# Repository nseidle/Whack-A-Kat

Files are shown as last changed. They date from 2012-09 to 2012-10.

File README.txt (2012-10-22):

WAK-A-KAT was a project for Burning Man 2012. This is a reaction speed game based on the Wack-A-Mole game. 6 pipes stuck out of the ground about 3 feet tall. At the end of the two rows of pipes (three each) stood a gum ball dispenser. The dispenser was filled full of cat foot.

On the end of each pipe was a large carnival button. Buttons would randomly illuminate and the player would have to hit the button(s) as fast as they could. Throughout the night the game would average the scores together. If you had a score that was better than the average (less total time to complete the game), then you won! And the gum ball dispenser, modified with a continuous servo, would dispense an amount of dry cat food. Yum!

This project was one of the first where I used the Arduino Mega 2560. The PCB layout is a decent example of a shield design for the Mega.

I also used Bill Porter's MP3 library: http://www.billporter.info/sparkfun-mp3-shield-arduino-library/
You rock Bill!

Each pipe was wrapped in EL wire. This provided a level of safety but used quite a bit more power than I predicted causing the 12V battery to drain before the night was over. Lesson: measure your project's power usage before you assume a brick of a battery will do the job.

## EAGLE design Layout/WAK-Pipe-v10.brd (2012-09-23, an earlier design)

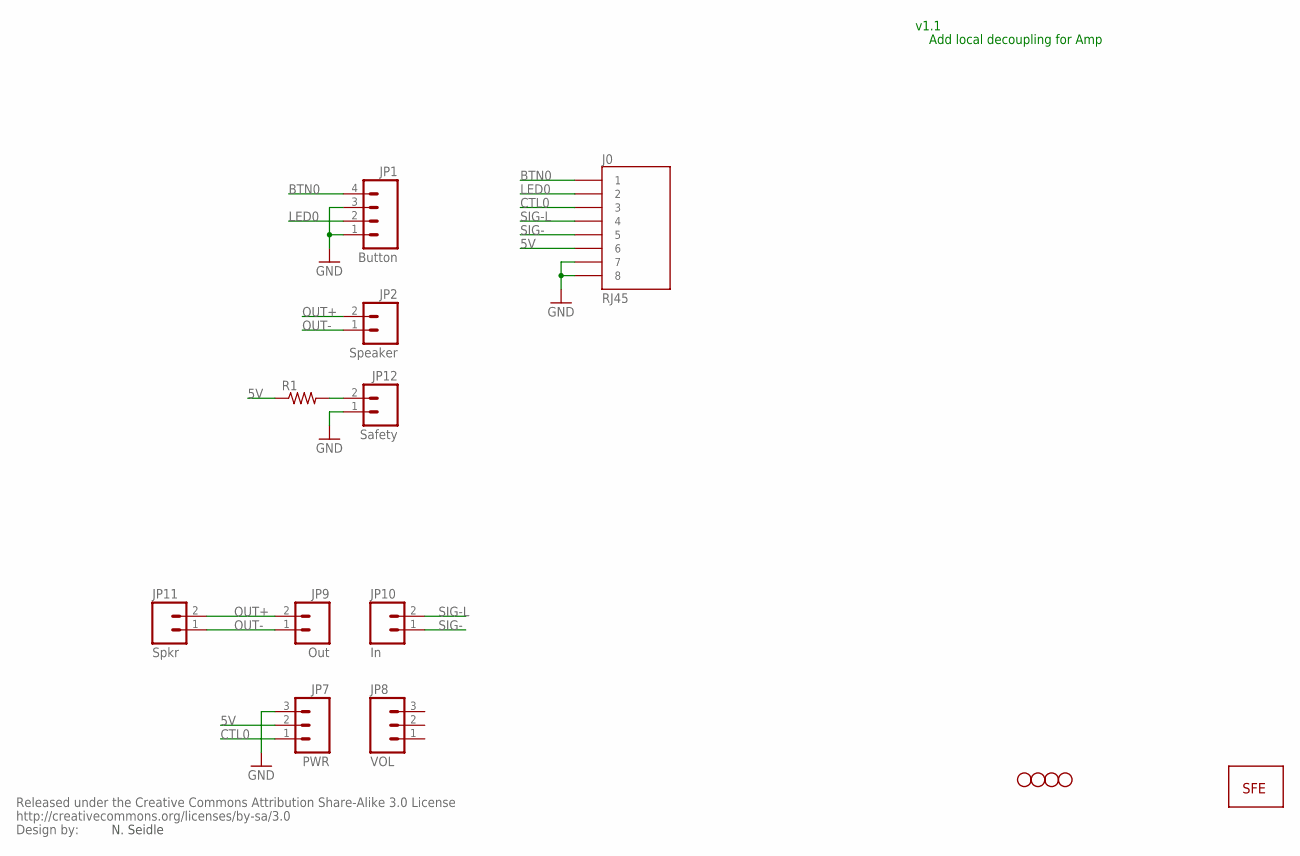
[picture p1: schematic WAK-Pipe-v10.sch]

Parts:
J0: RJ45; RJ45-8
JP1: Button; JST-4-PTH
JP2: Speaker; JST-2-PTH
JP3, JP4, JP5, JP6: STAND-OFF
JP7: PWR; 1X03
JP8: VOL; 1X03
JP9: Out; 1X02
JP10: In; 1X02
JP11: Spkr; 1X02
JP12: Safety; JST-2-PTH
R1: RESISTORAXIAL-0.3; AXIAL-0.3
U$1: LOGO-SFENEW; SFE-NEW-WEBLOGO
U$2: CREATIVE_COMMONS

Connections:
5V: J0.6, JP7.2, R1.P$1 (1)
BTN0: J0.1, JP1.4
CTL0: J0.3, JP7.1
GND: J0.7, J0.8, JP1.1, JP1.3, JP7.3, JP12.1
LED0: J0.2, JP1.2
unnamed: JP12.2, R1.P$2 (2)
OUT+: JP2.2, JP9.2, JP11.2
OUT-: JP2.1, JP9.1, JP11.1
SIG-: J0.5, JP10.1
SIG-L: J0.4, JP10.2

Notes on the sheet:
N. Seidle
v1.1
Add local decoupling for Amp

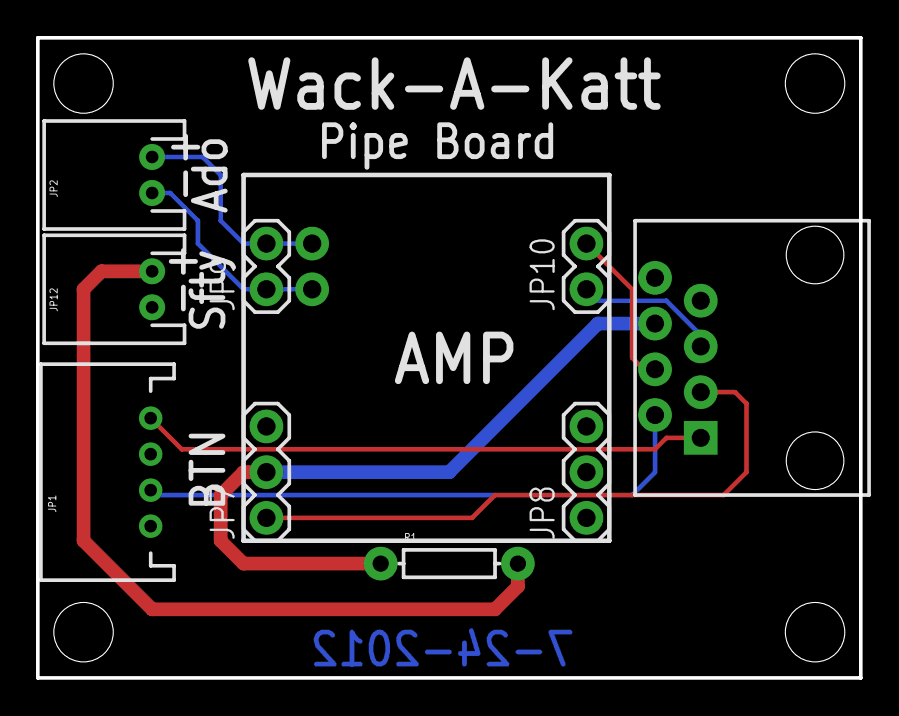
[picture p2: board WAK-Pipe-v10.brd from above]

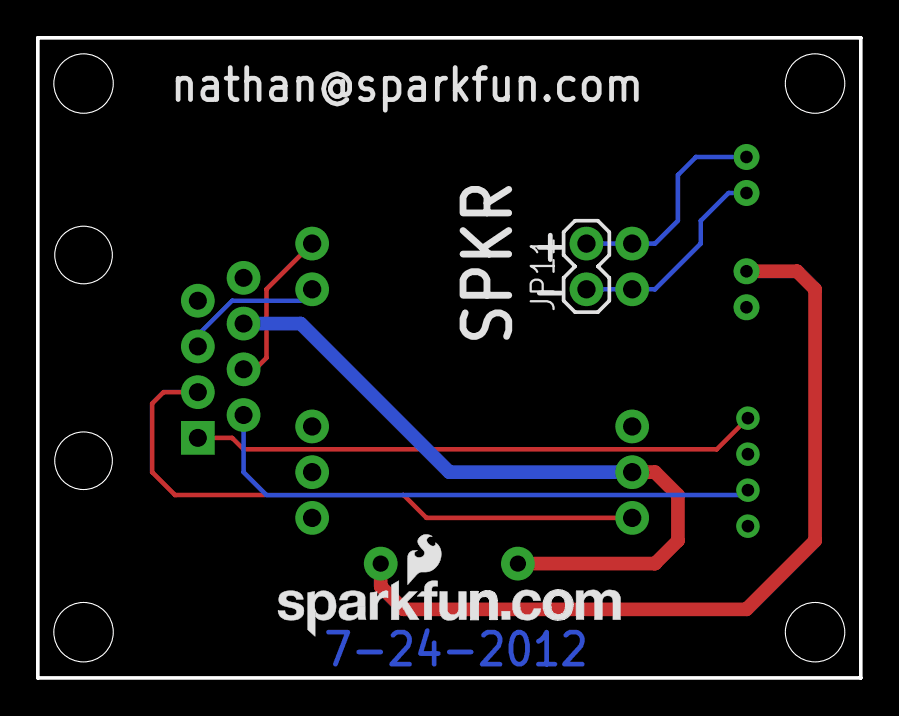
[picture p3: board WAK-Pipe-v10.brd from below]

Board: 2 copper layers, 45.7 x 35.6 mm, 16 parts (2 on the bottom side), 10 nets.

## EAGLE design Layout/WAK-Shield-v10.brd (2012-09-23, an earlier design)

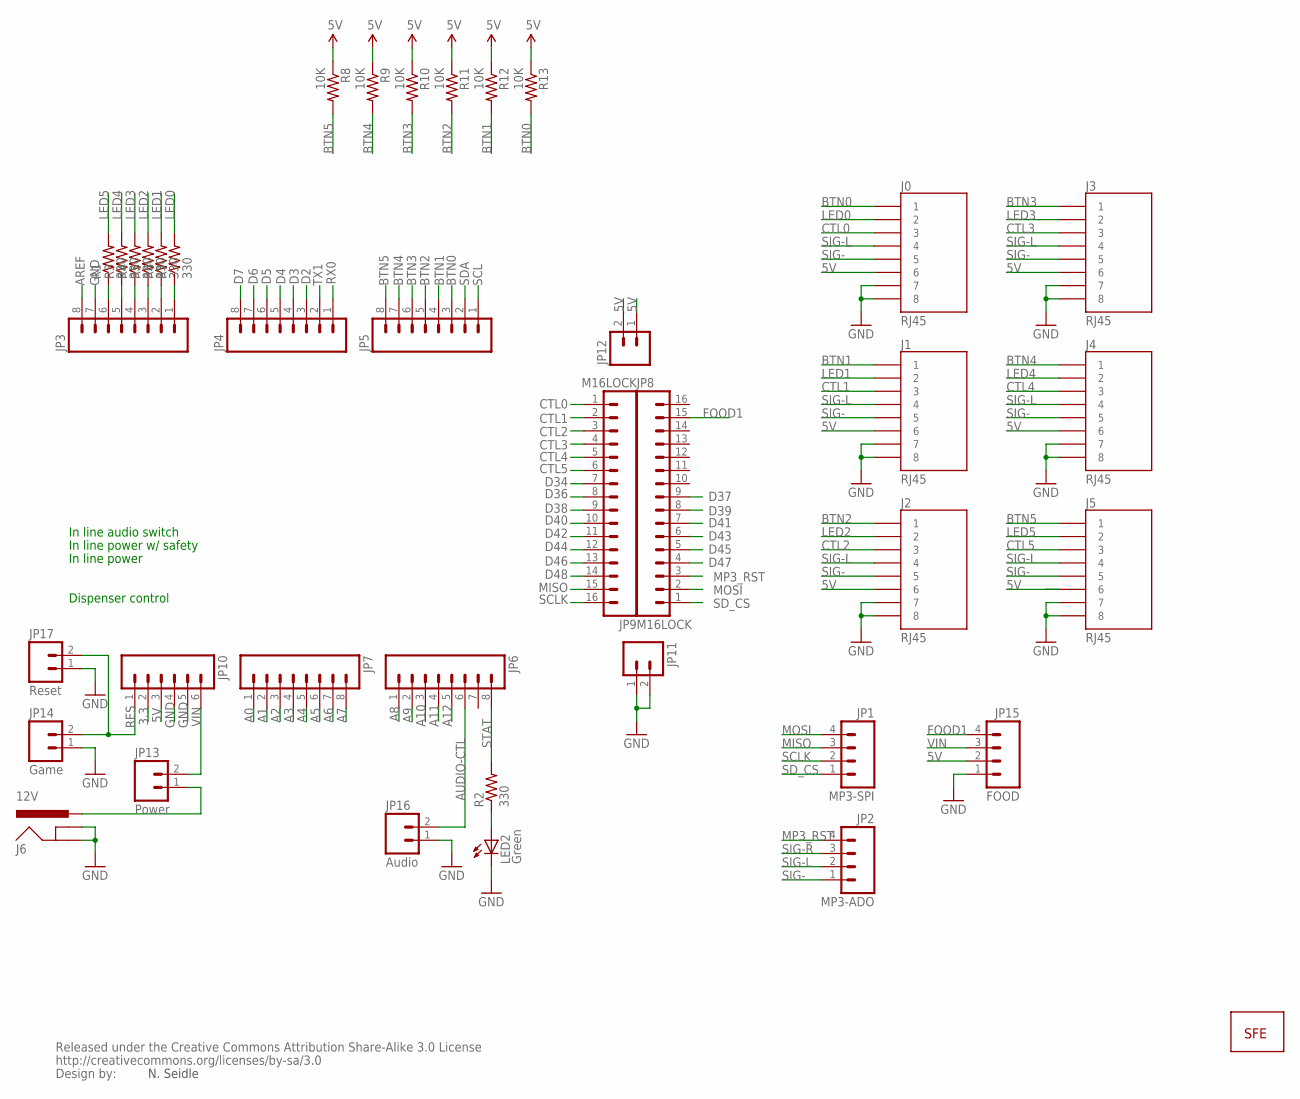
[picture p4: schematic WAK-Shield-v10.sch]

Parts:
J0, J1, J2, J3, J4, J5: RJ45; RJ45-8
J6: 12V; POWER_JACK_PTH_LOCK
JP1: MP3-SPI; JST-4-PTH
JP2: MP3-ADO; JST-4-PTH
JP3, JP4, JP5, JP6, JP7: M08LOCK; 1X08_LOCK
JP8, JP9: M16LOCK; 1X16_LOCK
JP10: M06LOCK; 1X06_LOCK
JP11, JP12: M02LOCK; 1X02_LOCK
JP13: Power; 1X02
JP14: Game; 1X02
JP15: FOOD; JST-4-PTH
JP16: Audio; 1X02
JP17: Reset; SCREWTERMINAL-3.5MM-2
LED2: Green; LED5MM
R1, R2, R3, R4, R5, R6, R7: 330; AXIAL-0.3
R8, R9, R10, R11, R12, R13: 10K; AXIAL-0.3
U$1: LOGO-SFENEW; SFE-NEW-WEBLOGO
U$2: CREATIVE_COMMONS

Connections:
3.3: JP10.2
5V: J0.6, J1.6, J2.6, J3.6, J4.6, J5.6, JP10.3, JP12.1, JP12.2, JP15.2, R8.P$1 (1), R9.P$1 (1), R10.P$1 (1), R11.P$1 (1), R12.P$1 (1), R13.P$1 (1)
A0: JP7.1
A1: JP7.2
A2: JP7.3
A3: JP7.4
A4: JP7.5
A5: JP7.6
A6: JP7.7
A7: JP7.8
A8: JP6.1
A9: JP6.2
A10: JP6.3
A11: JP6.4
A12: JP6.5
AREF: JP3.8
AUDIO-CTL: JP6.6, JP16.2
BTN0: J0.1, JP5.3, R13.P$2 (2)
BTN1: J1.1, JP5.4, R12.P$2 (2)
BTN2: J2.1, JP5.5, R11.P$2 (2)
BTN3: J3.1, JP5.6, R10.P$2 (2)
BTN4: J4.1, JP5.7, R9.P$2 (2)
BTN5: J5.1, JP5.8, R8.P$2 (2)
CTL0: J0.3, JP9.1
CTL1: J1.3, JP9.2
CTL2: J2.3, JP9.3
CTL3: J3.3, JP9.4
CTL4: J4.3, JP9.5
CTL5: J5.3, JP9.6
D2: JP4.3
D3: JP4.4
D4: JP4.5
D5: JP4.6
D6: JP4.7
D7: JP4.8
D34: JP9.7
D36: JP9.8
D37: JP8.9
D38: JP9.9
D39: JP8.8
D40: JP9.10
D41: JP8.7
D42: JP9.11
D43: JP8.6
D44: JP9.12
D45: JP8.5
D46: JP9.13
D47: JP8.4
D48: JP9.14
FOOD1: JP8.15, JP15.4
GND: J0.7, J0.8, J1.7, J1.8, J2.7, J2.8, J3.7, J3.8, J4.7, J4.8, J5.7, J5.8, J6.GND, J6.GNDBREAK, JP3.7, JP10.4, JP10.5, JP11.1, JP11.2, JP14.1, JP15.1, JP16.1, JP17.1, LED2.K (C)
LED0: J0.2, R7.P$2 (2)
LED1: J1.2, R6.P$2 (2)
LED2: J2.2, R5.P$2 (2)
LED3: J3.2, R4.P$2 (2)
LED4: J4.2, R3.P$2 (2)
LED5: J5.2, R1.P$2 (2)
MISO: JP1.3, JP9.15
MOSI: JP1.4, JP8.2
MP3_RST: JP2.4, JP8.3
unnamed: JP3.6, R1.P$1 (1)
unnamed: JP3.5, R3.P$1 (1)
unnamed: JP3.4, R4.P$1 (1)
unnamed: JP3.3, R5.P$1 (1)
unnamed: JP3.2, R6.P$1 (1)
unnamed: JP3.1, R7.P$1 (1)
unnamed: J6.PWR, JP13.1
unnamed: LED2.A, R2.P$1 (1)
RES: JP10.1, JP14.2, JP17.2
RX0: JP4.1
SCL: JP5.1
SCLK: JP1.2, JP9.16
SDA: JP5.2
SD_CS: JP1.1, JP8.1
SIG-: J0.5, J1.5, J2.5, J3.5, J4.5, J5.5, JP2.1
SIG-L: J0.4, J1.4, J2.4, J3.4, J4.4, J5.4, JP2.2
SIG-R: JP2.3
STAT: JP6.8, R2.P$2 (2)
TX1: JP4.2
VIN: JP10.6, JP13.2, JP15.3

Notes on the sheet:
N. Seidle
In line audio switch
In line power w/ safety
In line power
Dispenser control

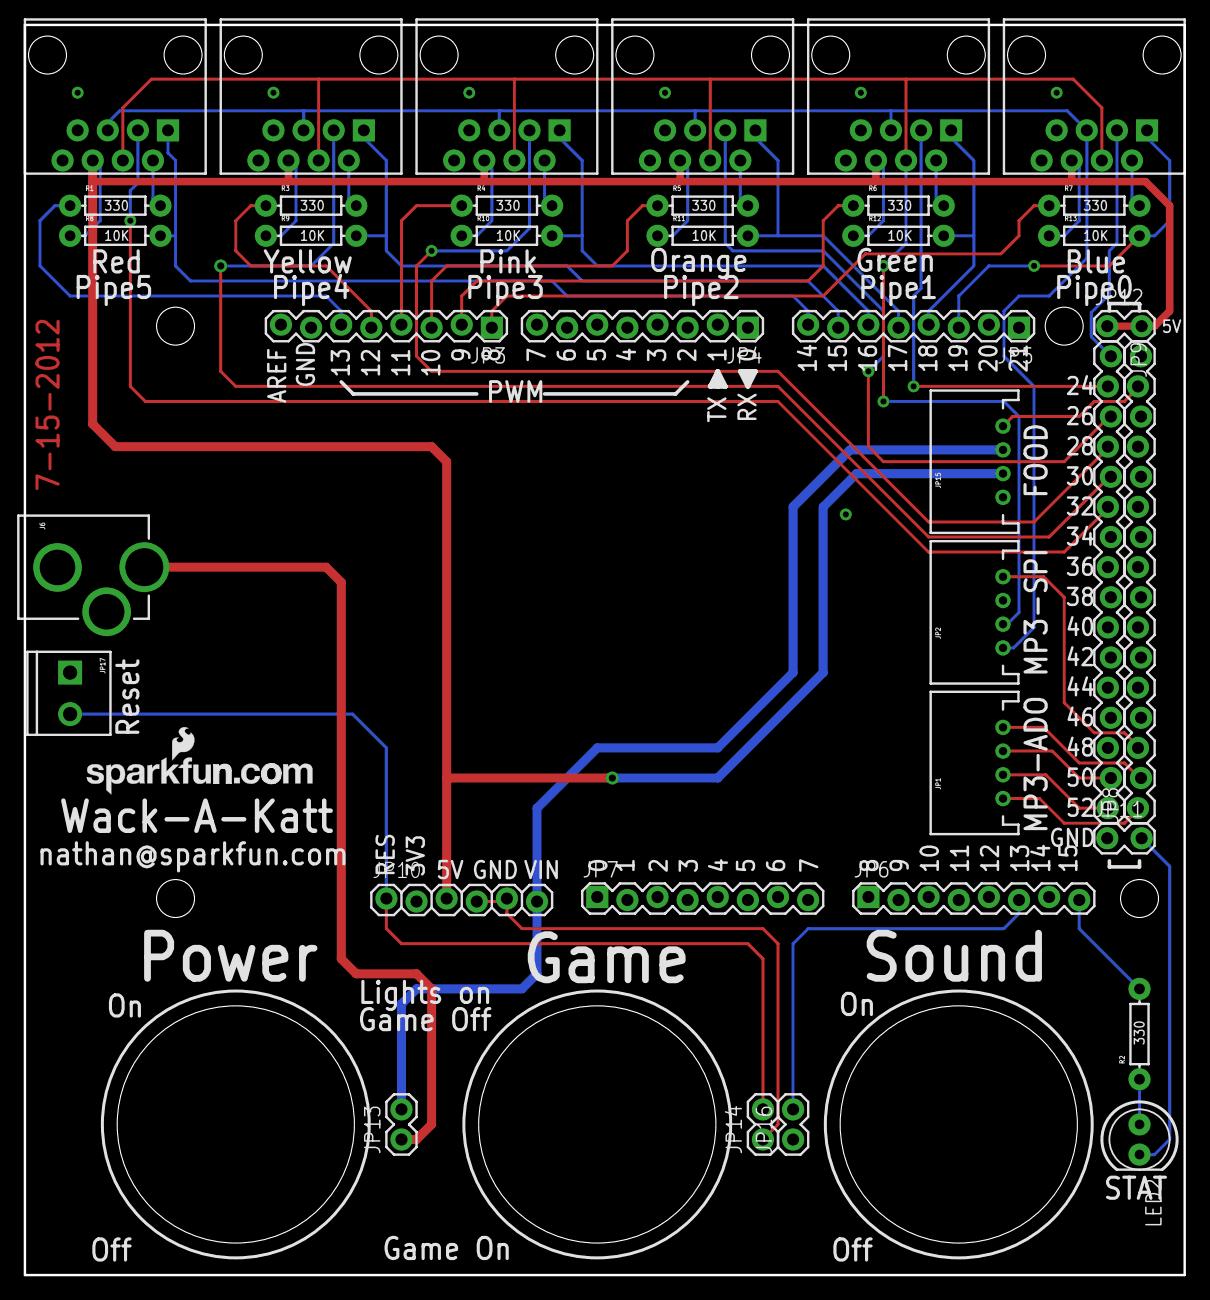
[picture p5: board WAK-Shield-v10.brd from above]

Board: 2 copper layers, 97.8 x 105.4 mm, 40 parts (0 on the bottom side), 40 nets.

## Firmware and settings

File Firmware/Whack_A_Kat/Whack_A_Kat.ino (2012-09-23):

/*
 4-28-2011
 Spark Fun Electronics 2011
 Nathan Seidle
 
 This code is public domain but you buy me a beer if you use this and we meet someday (Beerware license).
 
 This uses Bill Porter's exellent MP3 Shield Library
 
 There are 30 phases to WAK. Phase 1 has 1 button at a time and by phase 20 there are multiple buttons going
 at same time.
 
 Based on reaction time, the dispenser runs for different amounts of time.
 */

#include <SPI.h>

//Add the SdFat Libraries
#include <SdFat.h>
#include <SdFatUtil.h> 

#include <Servo.h> 

//and the MP3 Shield Library
#include <SFEMP3Shield.h>

//Create and name the library object
SFEMP3Shield MP3player;

//Create servo object
Servo foodServo;

//byte temp;
byte MP3result;

#define number_of_buttons  6 //The number of buttons available to hit
#define number_of_rounds 8 //The number of rounds the game will last

//We have to turn down the volume when all the cats are on otherwise the system will reset
//We can turn up the volume when individual cats are activated
#define ONECAT_VOLUME  30 //40 is ok, 20 is pretty stinking loud
#define ALLCAT_VOLUME  60 //Less then 60 and system will reset

//#define FOOD_AMOUNT 6700 //Three servings
#define FOOD_AMOUNT 6700/2 //Two servings
//#define FOOD_AMOUNT 6700/3 //One serving

int levels[number_of_rounds][number_of_buttons]; //Game board array
int level_times[number_of_rounds]; //Keeps track of each round time

int currentLevel = 0; //goes all the way to game_length
int hitErrors; //Keeps track of how many buttons you hit that *aren't* lit up
long totalGameTime; //Total millis the user has used up

long timeSinceLastGame; //Don't let folks start a game quicker than every 10 seconds
//long minTimeBetweenGames = 10000; //# of milliseconds we need to wait between games, 10,000 = 10 seconds
long minTimeBetweenGames = 100; //# of milliseconds we need to wait between games, 10,000 = 10 seconds

char tempString[100]; //Used for the sprintf based debug statements

long overallScoreTotal; //This is the total of all the scores played since power up. Used for average game score
long gamesPlayed; //Number of games played since power on. Used for average game score


//Hardware connections
//-=-=-=-=-=-=-=-=-=-=-=-=-=-=-=-=-=-=-=-=-=-=-=-=-=-=-=-=-=-=
int led0 = 8;
int led1 = 9;
int led2 = 10;
int led3 = 11;
int led4 = 12;
int led5 = 13;

int cat0 = 22; //Control to the first pipe amp (aka Cat #0)
int cat1 = 24;
int cat2 = 26;
int cat3 = 28;
int cat4 = 30;
int cat5 = 32;

int button0 = 19;
int button1 = 18;
int button2 = 17;
int button3 = 16;
int button4 = 15;
int button5 = 14;

//int foodControl = 25;
int gameControl = A7;
int audioControl = A13;
int statLED = A15;

//-=-=-=-=-=-=-=-=-=-=-=-=-=-=-=-=-=-=-=-=-=-=-=-=-=-=-=-=-=-=


void setup() {

  Serial.begin(115200);
  Serial.println("Whack-A-Kat v1.0");

  randomSeed(A5);

  pinMode(led0, OUTPUT);
  pinMode(led1, OUTPUT);
  pinMode(led2, OUTPUT);
  pinMode(led3, OUTPUT);
  pinMode(led4, OUTPUT);
  pinMode(led5, OUTPUT);

  pinMode(cat0, OUTPUT);
  pinMode(cat1, OUTPUT);
  pinMode(cat2, OUTPUT);
  pinMode(cat3, OUTPUT);
  pinMode(cat4, OUTPUT);
  pinMode(cat5, OUTPUT);

  pinMode(statLED, OUTPUT);
  //  pinMode(foodControl, OUTPUT);

  pinMode(button0, INPUT);
  pinMode(button1, INPUT);
  pinMode(button2, INPUT);
  pinMode(button3, INPUT);
  pinMode(button4, INPUT);
  pinMode(button5, INPUT);

  pinMode(audioControl, INPUT);
  pinMode(gameControl, INPUT);

  //Enable pull ups
  digitalWrite(button0, HIGH);
  digitalWrite(button1, HIGH);
  digitalWrite(button2, HIGH);
  digitalWrite(button3, HIGH);
  digitalWrite(button4, HIGH);
  digitalWrite(button5, HIGH);
  digitalWrite(audioControl, HIGH);
  digitalWrite(gameControl, HIGH);

  //Set outputs
  catsOff(); //Turn off all cats

  //boot up the MP3 Player Shield
  MP3result = MP3player.begin();
  //check result, see readme for error codes.
  if(MP3result != 0) {
    Serial.print("Error code: ");
    Serial.print(MP3result);
    Serial.println(" when trying to start MP3 player");
  }

  MP3player.SetVolume(ALLCAT_VOLUME, ALLCAT_VOLUME); //System runs with all 6 on

  overallScoreTotal = 0; //Reset total scores
  gamesPlayed = 0; //Reset games played

  //Test routine - not for production code
  //testRoutine();

  //dispenseFood();
}

void loop() {

  if(digitalRead(gameControl) == LOW) {
    Serial.println("Game is now turned off");
    while(digitalRead(gameControl) == LOW){ //Don't play if the switch is flipped
      digitalWrite(statLED, HIGH);
      delay(1000);
      digitalWrite(statLED, LOW);
      delay(1000);
    }
    Serial.println("Game on!");
  }

  waitForStart(); //Wait for someone to hit a button to begin the game

  startGame(); //Play start squence of noise and LED blinking

  populateTheGame(); //load random #s into the game array

  playTheGame(); //Play the game until levels are complete

  gameOver(); //Game is now complete! Print score, dispense cat food, play music

  timeSinceLastGame = millis(); //Remember what the time is so that folks don't start a new game too quickly
}

//Light up LEDs on the buttons
//If you hit the button, clear that button from array and turn off LED
//Record total time
//If time expires, record time and advance to next phase
void playTheGame(void) {

  //Restart the game
  totalGameTime = 0;
  currentLevel = 0;
  hitErrors = 0;

  //Now set volume for individual cat sounds
  //System dies when we set the volume too loud and turn on all speakers
  //This can be louder because we're only going to turn one on at a time
  MP3player.SetVolume(ONECAT_VOLUME, ONECAT_VOLUME);

  //Play the game until the levels are done
  while(currentLevel < number_of_rounds) {
    sprintf(tempString, "Begin Level: %d", currentLevel);
    Serial.print(tempString);

    if(MP3player.isPlaying() == false) catsOff(); //Turn off all the cats if no MP3 is playing

    //We need some off time of the LEDs so that people understand the buttons are on/off
    for(int ledNum = 0 ; ledNum < number_of_buttons ; ledNum++) controlLED(ledNum, LOW);
    delay(500);

    //Determine the number of buttons this round requires
    int hitsNeeded = 0;
    for(int x = 0 ; x < number_of_buttons ; x++) 
      if(levels[currentLevel][x] == 1) hitsNeeded++;

    //Light up button(s) for a certain amount of time
    //Serial.println("Lighting buttons");
    for(int ledNum = 0 ; ledNum < number_of_buttons ; ledNum++) {
      if(levels[currentLevel][ledNum] == 1) //light it up!
        controlLED(ledNum, HIGH);
      else
        controlLED(ledNum, LOW);
    }

    //Look up the max time for this round
    int maxRoundTime = level_times[currentLevel]; 

    long levelStartTime = millis(); //Start the response timer

    boolean catPlaying = false; //No cat sounds should be playing

    //Check the buttons against the game array
    //Clearing successful hits as we go
    //Serial.println("Monitoring buttons");
    while(hitsNeeded) {
      if(MP3player.isPlaying() == false) catsOff(); //Turn off all the cats if no MP3 is playing

      if(millis() - levelStartTime > maxRoundTime){ //You are too slow!
        Serial.print(" Too slow! ");

        //Turn off LEDs
        for(int ledNum = 0 ; ledNum < number_of_buttons ; ledNum++) controlLED(ledNum, LOW);

        //Penalty for not completing level
        hitErrors += hitsNeeded; //You now have whatever hits are left added to your error count

        break; //Goto next level
      }

      int buttonState[number_of_buttons]; //Records what buttons are pressed

      //Check the state of buttons
      for(int x = 0 ; x < number_of_buttons ; x++)
        buttonState[x] = checkButton(x);

      for(int x = 0 ; x < number_of_buttons ; x++) {

        if(buttonState[x] == LOW) { //You've hit one of the buttons!
          if(levels[currentLevel][x] == 1){ //This button needs to be pressed
            sprintf(tempString, " Button %d hit! ", x);
            Serial.print(tempString);

            //play cat sound
            if(catPlaying == false) {
              playCat(x);
              catPlaying = true;
            }

            //Debounce the button
            //while(checkButton(x) == LOW) ; //Wait for you to stop pressing the button

            //Turn off button LED
            controlLED(x, LOW);

            hitsNeeded--;
            levels[currentLevel][x] = 2; //Mark this button as pressed
          }
          else if (levels[currentLevel][x] == 2) {
            //Do nothing, this is just you holding the button for too long

          }
          else { //This button doesn't need to be pressed but you hit it!
            Serial.print(" Bad hit! ");

            //play horn sound

            //Debounce the button
            while(checkButton(x) == LOW) ; //Wait for you to stop pressing the button

            hitErrors++;
          }
        } //End check this button state
      }

    } //End hitsNeeded checking

    //Once we are here, we have completed this level
    currentLevel++; //Advance to next level
    Serial.println(); //We are done printing this level info

    totalGameTime += (millis() - levelStartTime); //Add this level's time onto the total time
  }

}

//Given a number, plays a cat track
//Stops any previous track that may be playing
void playCat(int catNumber) {
  if(MP3player.isPlaying()) MP3player.stopTrack(); //Stop any previous track

  if(digitalRead(audioControl) == LOW) { //Check to see if we should turn off the sounds
    if(catNumber == 0) {
      selectCat(0);
      MP3player.playMP3("cat1.mp3");
    }
    if(catNumber == 1){
      selectCat(1);
      MP3player.playMP3("cat2.mp3");
    }
    if(catNumber == 2){
      selectCat(2);
      MP3player.playMP3("cat3.mp3");
    }
    if(catNumber == 3) {
      selectCat(3);
      MP3player.playMP3("cat4.mp3");
    }
    if(catNumber == 4){
      selectCat(4);
      MP3player.playMP3("cat5.mp3");
    }
    if(catNumber == 5){
      selectCat(5);
      MP3player.playMP3("cat6.mp3");
    }
    //delay(1000);
  } 
  else
    Serial.print("Sound off!");
}

//Plays a 3 second count down with LED blinks
//Blinks LEDs while we go
void startGame(void) {
  Serial.println();
  Serial.println("Begin new game!");

  Serial.print("Get ready: ");

  //Initially turn off LEDs
  for(int led = 0 ; led < number_of_buttons ; led++)
    controlLED(led, LOW);
  delay(250);

  for(int x = 0 ; x < 3 ; x++) {
    long startTime = millis();

    Serial.print(3 - x);
    Serial.print(",");

    //Turn on all LEDs
    for(int led = 0 ; led < number_of_buttons ; led++)
      controlLED(led, HIGH);

    //Play normal Beep!
    if(digitalRead(audioControl) == LOW) { //Check to see if we should turn off the sounds
      catsOn(); //Turn on all the cats
      MP3player.playMP3("beep.mp3");
    }

    delay(250);

    //Turn off LEDs
    for(int led = 0 ; led < number_of_buttons ; led++)
      controlLED(led, LOW);

    while(millis() - startTime < 500) ; //Wait for a half second each time around
  }

  //Turn on all LEDs
  for(int led = 0 ; led < number_of_buttons ; led++)
    controlLED(led, HIGH);

  //Play long Beep!
/*  if(digitalRead(audioControl) == LOW) //Check to see if we should turn off the sounds
    MP3player.playMP3("Cougar.mp3");
  delay(1000);
  MP3player.stopTrack();*/

  //while(MP3player.isPlaying()) ; //Wait for MP3 to finish playing before turning off all cats
  catsOff(); //Turn off all the cats

  //Turn off LEDs
  for(int led = 0 ; led < number_of_buttons ; led++)
    controlLED(led, LOW);

  Serial.println();
  Serial.println("Go!");

  delay(1000); //Wait one more second before we begin
}

//Pulses the button LEDs on/off to try to entice someone to play with me!!!!
void waitForStart(void) {
  catsOff(); //Turn off the cats while we wait!

  Serial.println();
  Serial.println("Waiting for you to hit a button...");

  while(1) {

    //Bring LEDs up in brightness
    for(int fadeValue = 0 ; fadeValue <= 255; fadeValue +=5) {

      //Assign all the LEDs the same value
      for(int ledNum = 0 ; ledNum < number_of_buttons ; ledNum++) {
        if(checkButton(ledNum) == LOW){ //Someone wants to play!
          if(millis() - timeSinceLastGame > minTimeBetweenGames) //Make sure enough time has passed
            return;
          else
            Serial.println("Too soon!");
        }

        controlLEDanalog(ledNum, fadeValue);
      }

      delay(30);
    } 

    //Bring LEDs down in brightness
    for(int fadeValue = 255 ; fadeValue >= 0; fadeValue -=5) {

      //Assign all the LEDs the same value
      for(int ledNum = 0 ; ledNum < number_of_buttons ; ledNum++){
        if(checkButton(ledNum) == LOW){ //Someone wants to play!
          if(millis() - timeSinceLastGame > minTimeBetweenGames) //Make sure enough time has passed
            return;
          else
            Serial.println("Too soon!");
        }

        controlLEDanalog(ledNum, fadeValue);
      }

      delay(30);
    } 
  }
}

//Play win music to indicate game over
//Blink LEDs
//Print your time
//Dispense tasty food
void gameOver(void) {

  sprintf(tempString, "Game over! It took you %d seconds.", totalGameTime/1000);
  Serial.println(tempString);

  sprintf(tempString, "Hit errors: %d", hitErrors);
  Serial.println(tempString);

  long totalScore = totalGameTime + (hitErrors * 1000);
  sprintf(tempString, "Your score: %u", totalScore);
  Serial.println(tempString);

  overallScoreTotal += (long)totalScore; //Add this game to the total mix
  gamesPlayed++; //Increase the game count

  long avgScore = overallScoreTotal / gamesPlayed;

  Serial.print("overallScore: ");
  Serial.print(overallScoreTotal);
  Serial.print(" gamesPlayed: ");
  Serial.print(gamesPlayed);
  Serial.print(" avgScore: ");
  Serial.println(avgScore);

  //Play game music
  if (totalScore < avgScore) {

    //Set the MP3 volume softer so that we don't reset the system
    MP3player.SetVolume(ALLCAT_VOLUME, ALLCAT_VOLUME);

    if(MP3player.isPlaying()) MP3player.stopTrack(); //Stop any previous track

    //Play win music!
    if(digitalRead(audioControl) == LOW) { //Check to see if we should turn off the sounds
      catsOn(); //Turn on all cats
      MP3player.playMP3("win2.mp3");
    }
  }

  //Blink LEDs fast
  for(int x = 0 ; x < 10 ; x++) {
    //Turn on all LEDs
    for(int led = 0 ; led < number_of_buttons ; led++)
      controlLED(led, HIGH);

    delay(100);

    //Turn off LEDs
    for(int led = 0 ; led < number_of_buttons ; led++)
      controlLED(led, LOW);

    delay(100);
  }

  //Activate the food dispenser for some reward
  if (totalScore < avgScore) dispenseFood();

  catsOff();

}

//Turn on a continuous servo for a brief amount of time
void dispenseFood(void) {
  Serial.println("You win Food!");

  foodServo.attach(25);
  foodServo.writeMicroseconds(3000); //Turn servo counter clockwise
  delay(FOOD_AMOUNT); //The amount of time to adjust the dispenser one spot of food
  foodServo.writeMicroseconds(1500); //Stop servo from turning
  
  delay(1000); //Wait for servo to brake against momentum before detach

  foodServo.detach(); //Unplug servo from system
}

//Turn off all cats
void catsOff(void) {
  digitalWrite(cat0, LOW);
  digitalWrite(cat1, LOW);
  digitalWrite(cat2, LOW);
  digitalWrite(cat3, LOW);
  digitalWrite(cat4, LOW);
  digitalWrite(cat5, LOW);
}

//Turn all the cats (pipes) on at the same time
//Good for broadcasting a message or sound
void catsOn(void) {
  //We have to turn down the MP3 volume so the system doesn't reset
  //Anything less than 60 will cause system reset
  MP3player.SetVolume(ALLCAT_VOLUME, ALLCAT_VOLUME); //System runs with all 6 on

  digitalWrite(cat0, HIGH);
  digitalWrite(cat1, HIGH);
  digitalWrite(cat2, HIGH);
  digitalWrite(cat3, HIGH);
  digitalWrite(cat4, HIGH);
  digitalWrite(cat5, HIGH);
}

//Given the cat #, turn that cat (pipe) and only that cat on
void selectCat(int catNumber) {
  catsOff(); //Turn off all the other cats
  if(catNumber == 0) digitalWrite(cat0, HIGH);
  if(catNumber == 1) digitalWrite(cat1, HIGH);
  if(catNumber == 2) digitalWrite(cat2, HIGH);
  if(catNumber == 3) digitalWrite(cat3, HIGH);
  if(catNumber == 4) digitalWrite(cat4, HIGH);
  if(catNumber == 5) digitalWrite(cat5, HIGH);
}

//Given a button number, this will turn on or off an LED
void controlLED(int buttonNumber, int state) {
  if(buttonNumber == 0) digitalWrite(led0, state);
  if(buttonNumber == 1) digitalWrite(led1, state);
  if(buttonNumber == 2) digitalWrite(led2, state);
  if(buttonNumber == 3) digitalWrite(led3, state);
  if(buttonNumber == 4) digitalWrite(led4, state);
  if(buttonNumber == 5) digitalWrite(led5, state);
}

//Controls the button LEDs but with analog values rather than just on/off
void controlLEDanalog(int buttonNumber, int value) {
  if(buttonNumber == 0) analogWrite(led0, value);
  if(buttonNumber == 1) analogWrite(led1, value);
  if(buttonNumber == 2) analogWrite(led2, value);
  if(buttonNumber == 3) analogWrite(led3, value);
  if(buttonNumber == 4) analogWrite(led4, value);
  if(buttonNumber == 5) analogWrite(led5, value);
}

//Given a button number, this returns the state of that button
int checkButton(int buttonNumber) {

  if(buttonNumber == 0) return(digitalRead(button0));
  if(buttonNumber == 1) return(digitalRead(button1));
  if(buttonNumber == 2) return(digitalRead(button2));
  if(buttonNumber == 3) return(digitalRead(button3));
  if(buttonNumber == 4) return(digitalRead(button4));
  if(buttonNumber == 5) return(digitalRead(button5));

  Serial.print("Error: You shouldn't be here");
  return(0);  
}

/*
  if(Serial.available()){
 temp = Serial.read();
 
 Serial.print("Received command: ");
 Serial.write(temp);
 Serial.println(" ");
 
 //if s, stop the current track
 if (temp == 's') {
 MP3player.stopTrack();
 }
 else if (temp == 'c') {
 MP3player.playMP3("Cougar.mp3");
 
 //check result, see readme for error codes.
 if(result != 0) {
 Serial.print("Error code: ");
 Serial.print(result);
 Serial.println(" when trying to play track");
 }
 else
 Serial.println("Playing Cougar");
 }
 }
 */

void populateTheGame() {

  //Zero out the board
  for(int x = 0 ; x < number_of_rounds ; x++)
    for(int j = 0 ; j < number_of_buttons ; j++)
      levels[x][j] = 0;

  //Zero out the level times
  for(int x = 0 ; x < number_of_rounds ; x++)
    level_times[x] = 0;

  for(int roundNumber = 0 ; roundNumber < number_of_rounds ; roundNumber++) {

    //For the later rounds, assign more simultaneous buttons
    int spotsToAssign;
    if(roundNumber < 5) spotsToAssign = 1;
    else if(roundNumber < 20) spotsToAssign = 2;
    else if(roundNumber < 25) spotsToAssign = 3;
    else if(roundNumber < 30) spotsToAssign = 4;

    //Fill the game board with buttons
    if(spotsToAssign > number_of_buttons) spotsToAssign = number_of_buttons; //Correct for too few buttons

      do{
      for(int button = 0 ; button < number_of_buttons && spotsToAssign > 0 ; button++){
        if(random(number_of_buttons) == button){ //if our random number equals the button number then turn on this in the array
          levels[roundNumber][button] = 1;
          spotsToAssign--;
        }
      }
    } 
    while(spotsToAssign > 0);

    //Assign different round lengths to each round
    level_times[roundNumber] = random(700, 2200); //Set the level time between 1s and 2s

  }

  //Print the array
  Serial.println("Game:");
  for(int x = 0 ; x < number_of_rounds ; x++){
    sprintf(tempString, "Round %02d: ", x);
    Serial.print(tempString);

    for(int j = 0 ; j < number_of_buttons ; j++){
      if(levels[x][j] == 0)
        Serial.print("0 ");
      else
        Serial.print("1 ");
    }

    Serial.print("Round Time: ");
    Serial.print(level_times[x]);

    Serial.println();
  }

}

//Turns on each speaker and LED individually
void testRoutine(void) {
  
  while(1){
    for(int x = 0 ; x < number_of_buttons ; x++) {
      playCat(x);
      controlLED(x, HIGH);
      delay(1500);
      controlLED(x, LOW);
    }
    
  }
  
}

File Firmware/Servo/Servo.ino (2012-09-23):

#include <Servo.h> 
 
Servo foodServo;
 
int pos = 0;    // variable to store the servo position 
 
void setup() { 
  foodServo.attach(9);  // attaches the servo on pin 9 to the servo object 
}
 
 
void loop() { 
  foodServo.writeMicroseconds(3000); //Turn servo counter clockwise
  delay(6700); //For two seconds
  foodServo.writeMicroseconds(1500); //Stop servo from turning
  delay(2000);
}

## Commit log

2012-09-23 Last push before burning man
    This was the last update before burning man. Project worked well.
    [Mega_Shield-v13.brd, Mega_Shield-v13.sch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]
2012-10-22 Added Readme. Put files into directories.
    [Mega_Shield-v13.brd, Mega_Shield-v13.sch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]

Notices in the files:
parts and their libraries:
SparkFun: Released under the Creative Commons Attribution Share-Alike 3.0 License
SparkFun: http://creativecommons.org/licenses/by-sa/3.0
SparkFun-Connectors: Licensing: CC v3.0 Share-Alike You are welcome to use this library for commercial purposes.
